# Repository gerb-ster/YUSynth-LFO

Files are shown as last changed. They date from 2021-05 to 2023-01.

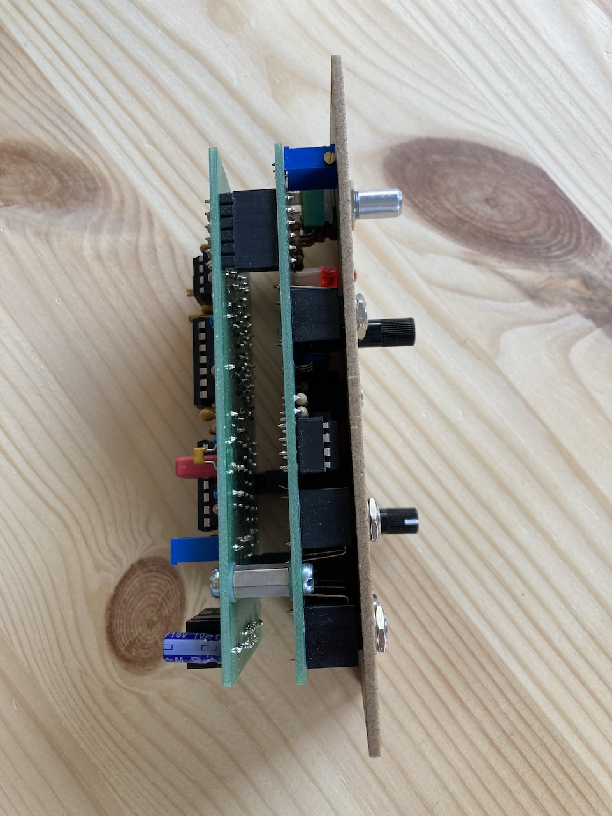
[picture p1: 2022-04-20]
images/IMG_1314.jpeg

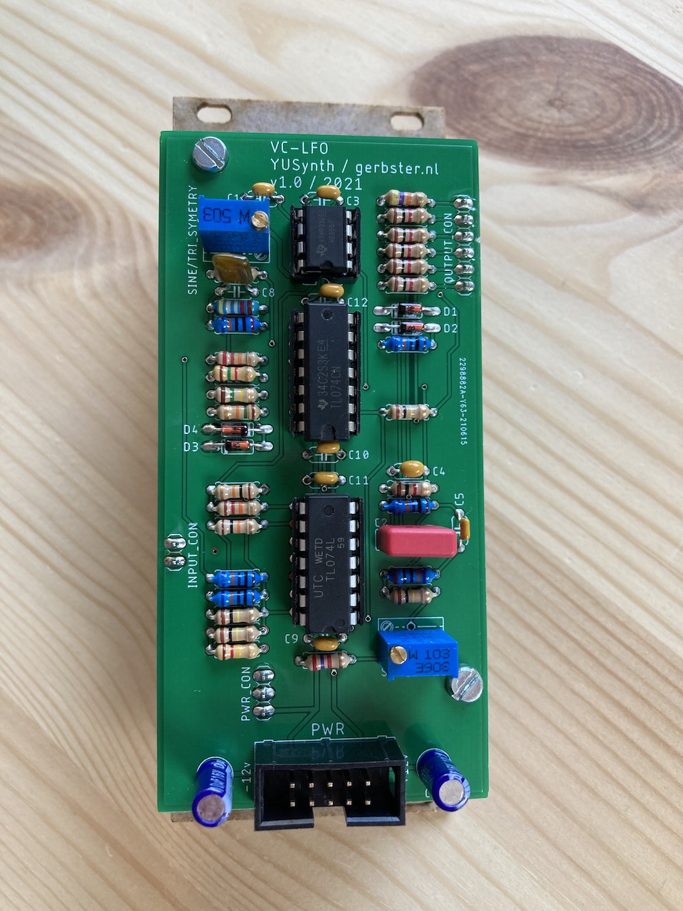
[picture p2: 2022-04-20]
images/IMG_1312.jpeg

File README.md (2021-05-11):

# YUSynth LFO

I'm working on some new modules, one of them is this VC-LFO adaptation from YUSynth. As far as I can determine this is a VCO that generates a saw waveform which is then run thru some wave shapers to create a saw, tri, pulse and sine wave.

I've made some modifications:

- I've powered it with +/- 12v instead of the +/- 15v.
- I've ommited the range switch section, after breadboarding it I found the range with the 1 uF cap quite sufficient.
- I also changed some resistor values to make sure the output is 10vpp around 0v for all waveforms.
- I rearranged the wave shapers a bit; the tri/sine section comes after the saw buffer, this way the tri/sine section outputs a 10vpp around 0v without the need for extra components.

In the YUSynth design there was 1 unused op-amp section; I've used that one to invert the saw into an extra ramp output.

The original design:
http://yusynth.net/Modular/EN/LFO/VC-LFO2.html

## Status: Work in Progress

- done: first schematic & board design
- done: breadboard and test
- done: design frontpanel
- todo: order PCB and build prototype

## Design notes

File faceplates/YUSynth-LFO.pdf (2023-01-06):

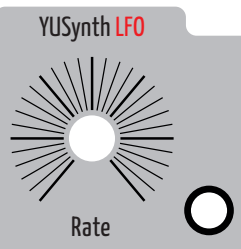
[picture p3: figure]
Rate; YUSynth LFO

Sync.

CV

+
PWM

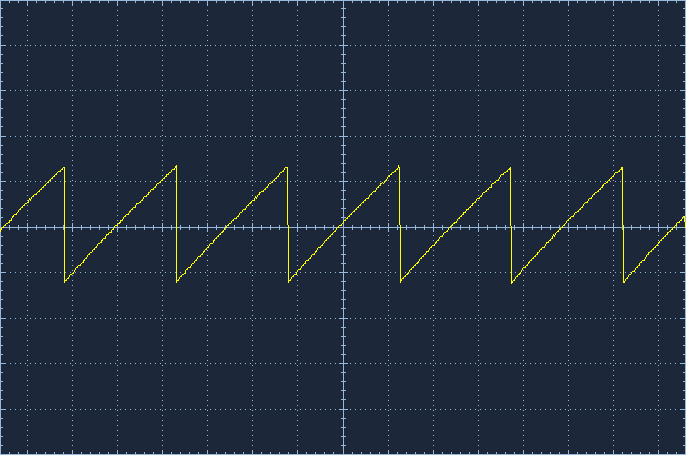
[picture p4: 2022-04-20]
images/saw.png

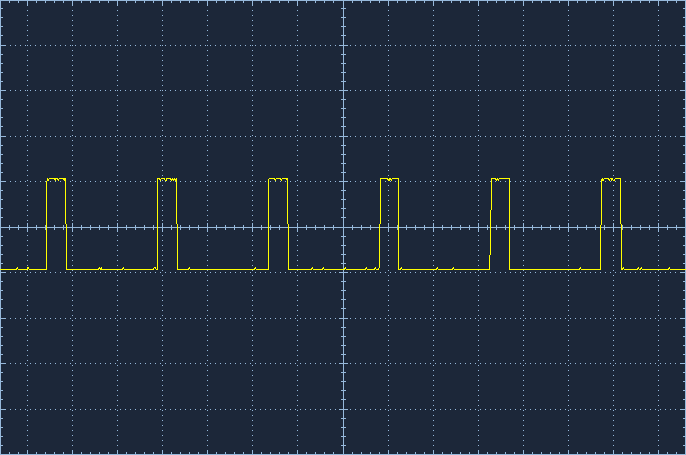
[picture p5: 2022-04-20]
images/pwm.png

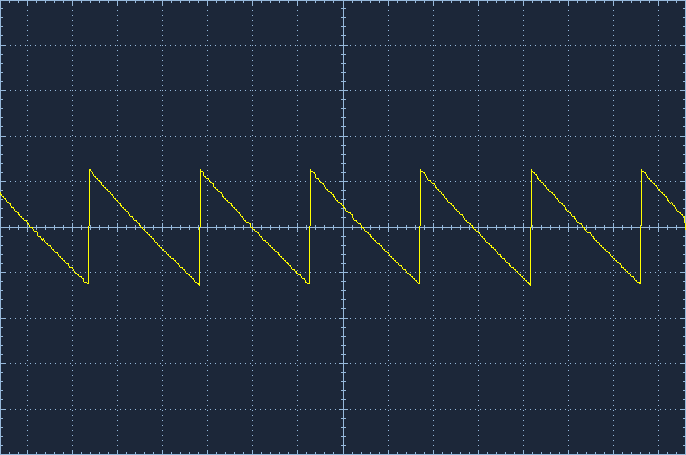
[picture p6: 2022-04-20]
images/r-saw.png

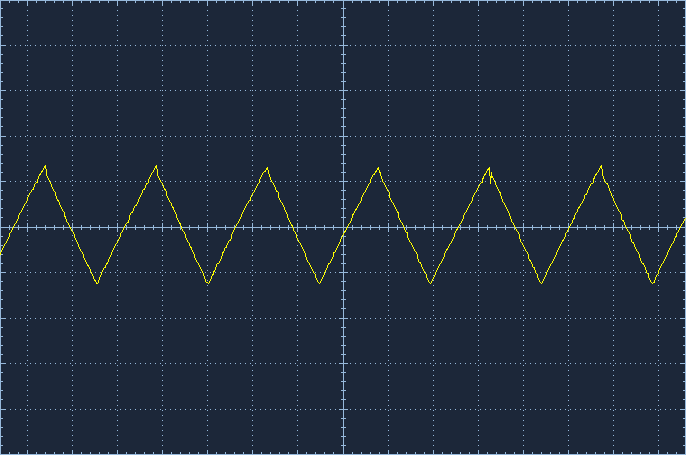
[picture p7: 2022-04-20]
images/tri.png

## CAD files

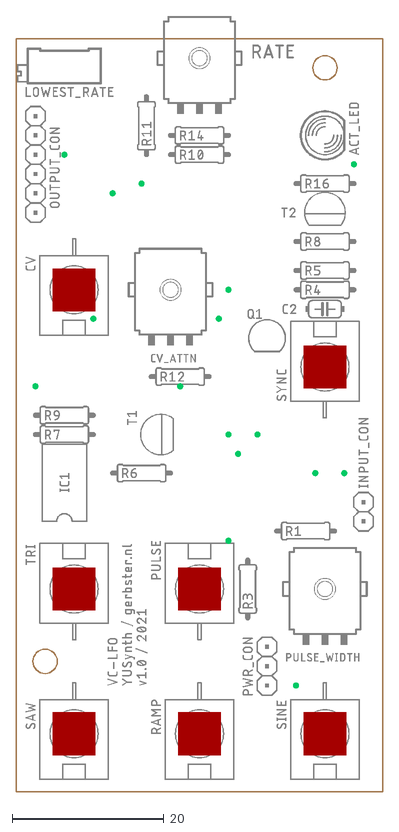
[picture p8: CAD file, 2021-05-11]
faceplates/ioboard.dxf
48.3 x 102.0

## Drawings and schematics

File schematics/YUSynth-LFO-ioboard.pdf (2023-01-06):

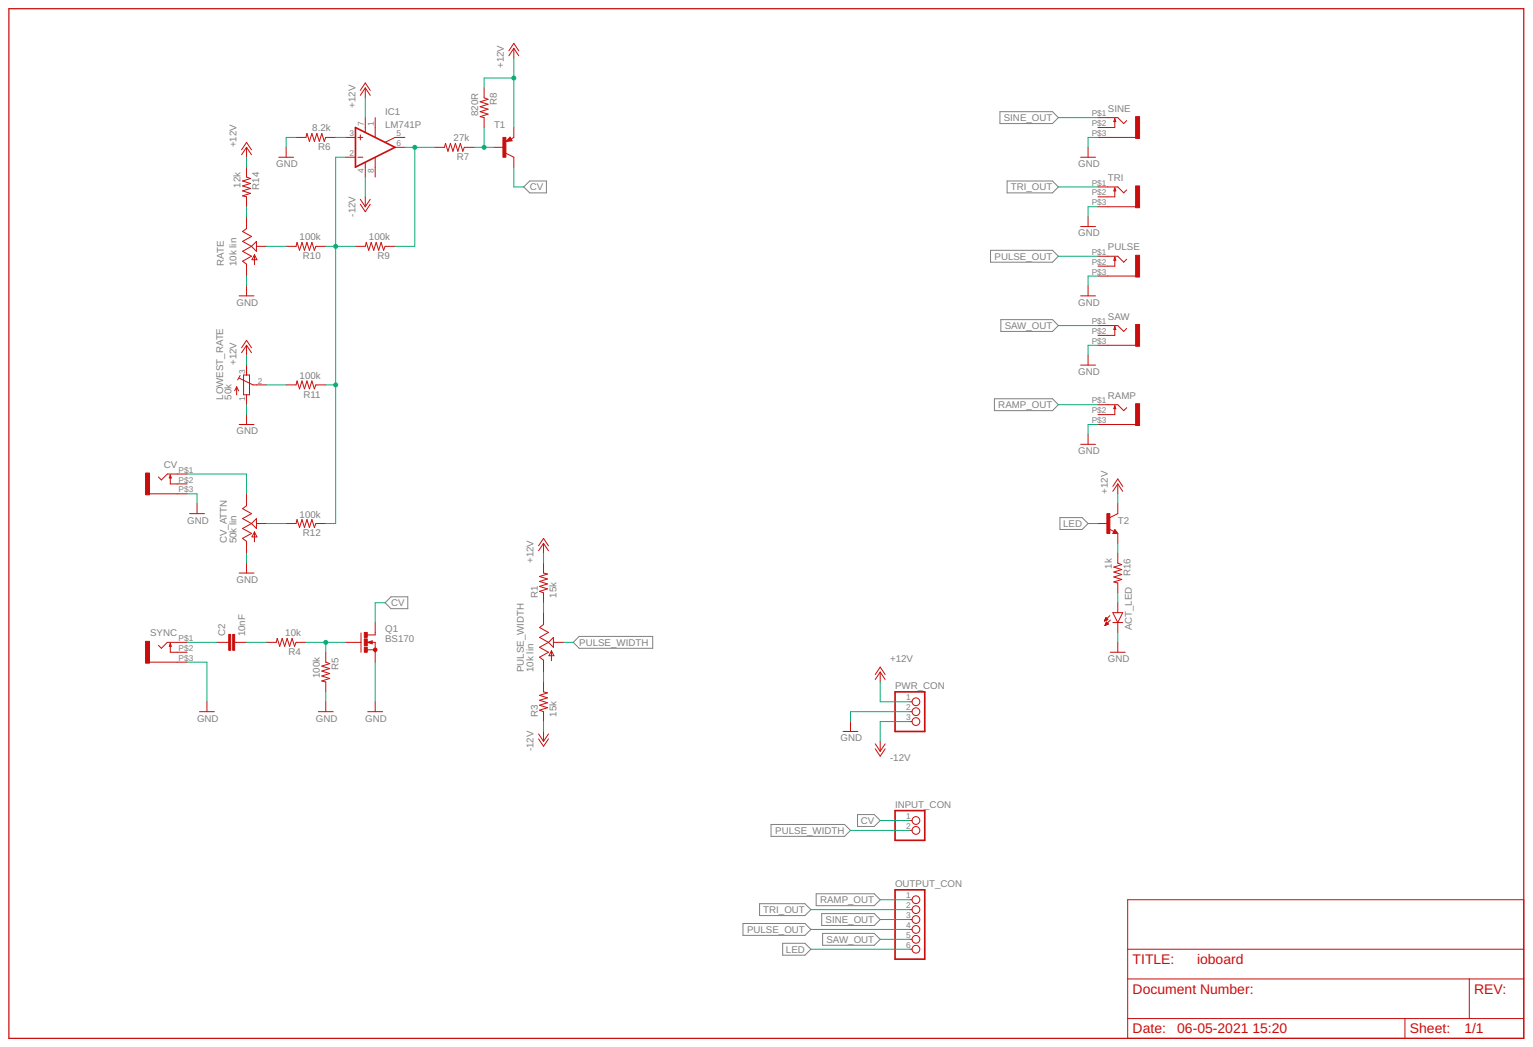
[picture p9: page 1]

15k LM741P +12V -12V GND 10k lin 15k +12V -12V BS170 10nF 10k 100k GND GND GND 8.2k GND 27k 820R 100k +12V 100k 100k 100k 10k lin 12k +12V GND 50k +12V GND 50k lGND in 1k GND +12V GND GND GND GND +12V -12V GND GND P$3 P$1 P$2 SYNC R1 5 1 23 6 8 7 4 IC1 T1 PULSE_WIDTH T2 ACT_LED R3 Q1 C2 R4 R5 R6 R7 R8 R10 R9 R11 R12 RATE R14 1 3 2 LOWEST_RATE P$3 P$1 P$2 CV CV_ATTN R16 P$3 P$1 P$2SINE P$3 P$1 P$2TRI P$3 P$1 P$2PULSE P$3 P$1 P$2SAW 123 PWR_CON P$3 P$1 P$2 RAMP 12 INPUT_CON 123456 OUTPUT_CON PULSE_WIDTH PULSE_WIDTH CV CV CV LED LED SINE_OUT SINE_OUT TRI_OUT TRI_OUT PULSE_OUT PULSE_OUT SAW_OUT SAW_OUT RAMP_OUT RAMP_OUT Date: Sheet: REV: TITLE: Document Number: 06-05-2021 15:20 1/1 ioboard

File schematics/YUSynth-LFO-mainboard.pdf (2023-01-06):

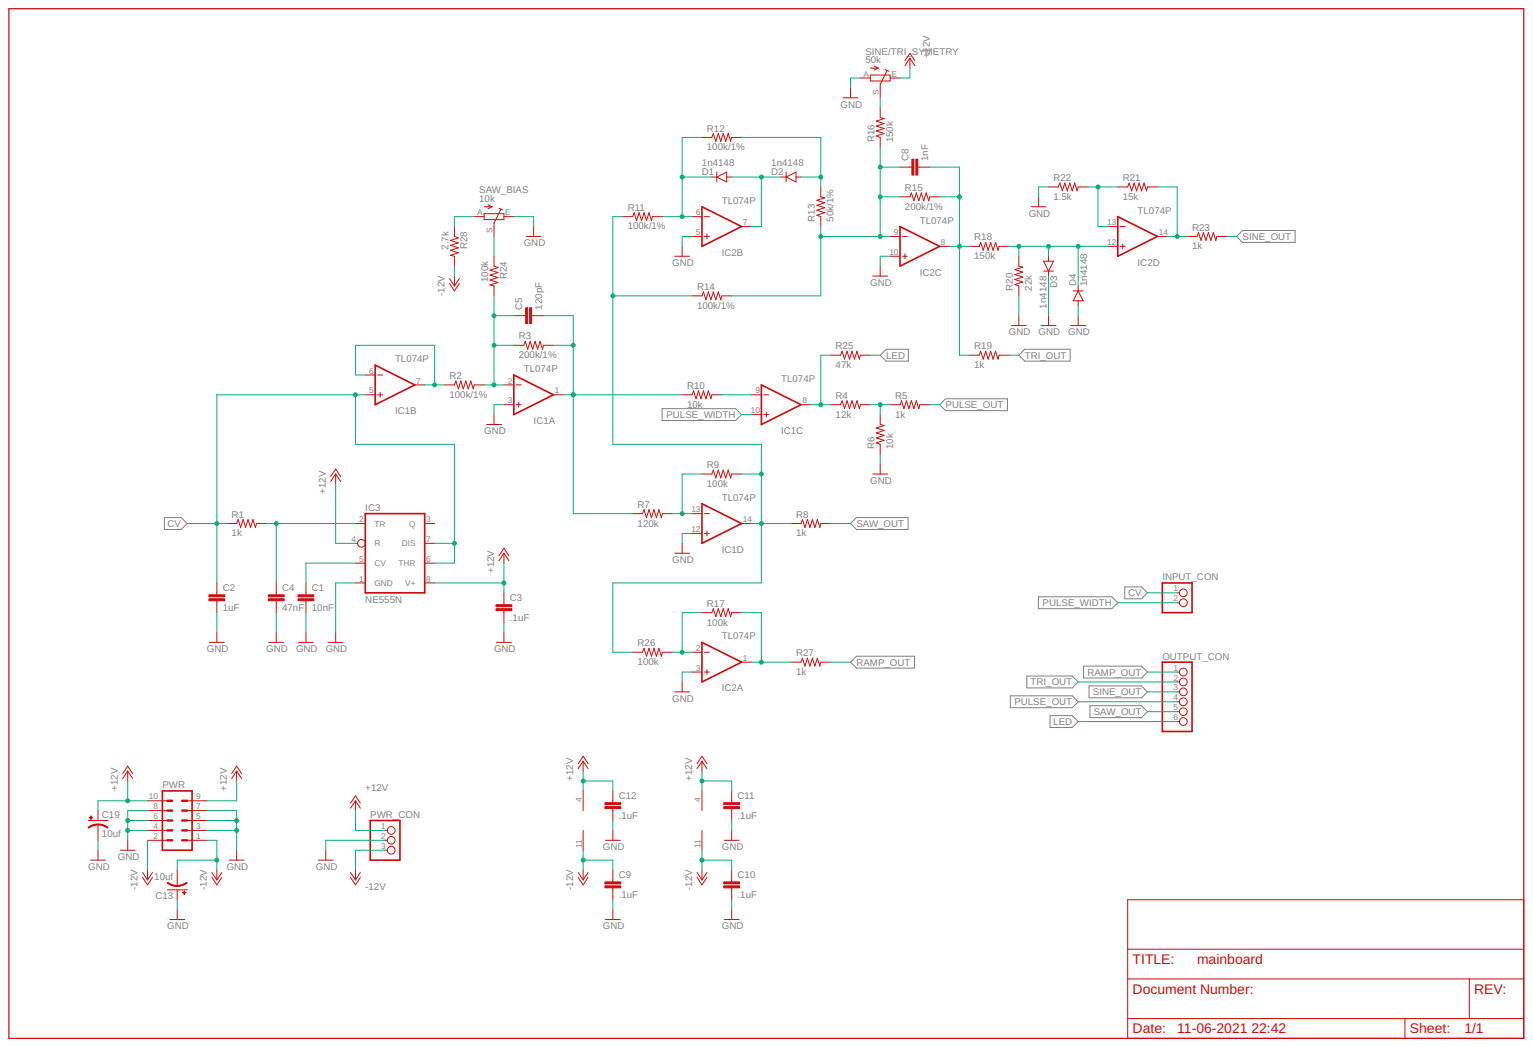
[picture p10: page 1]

Document Number: | REV:

Date: 11-06-2021 22:42 | Sheet: 1/1

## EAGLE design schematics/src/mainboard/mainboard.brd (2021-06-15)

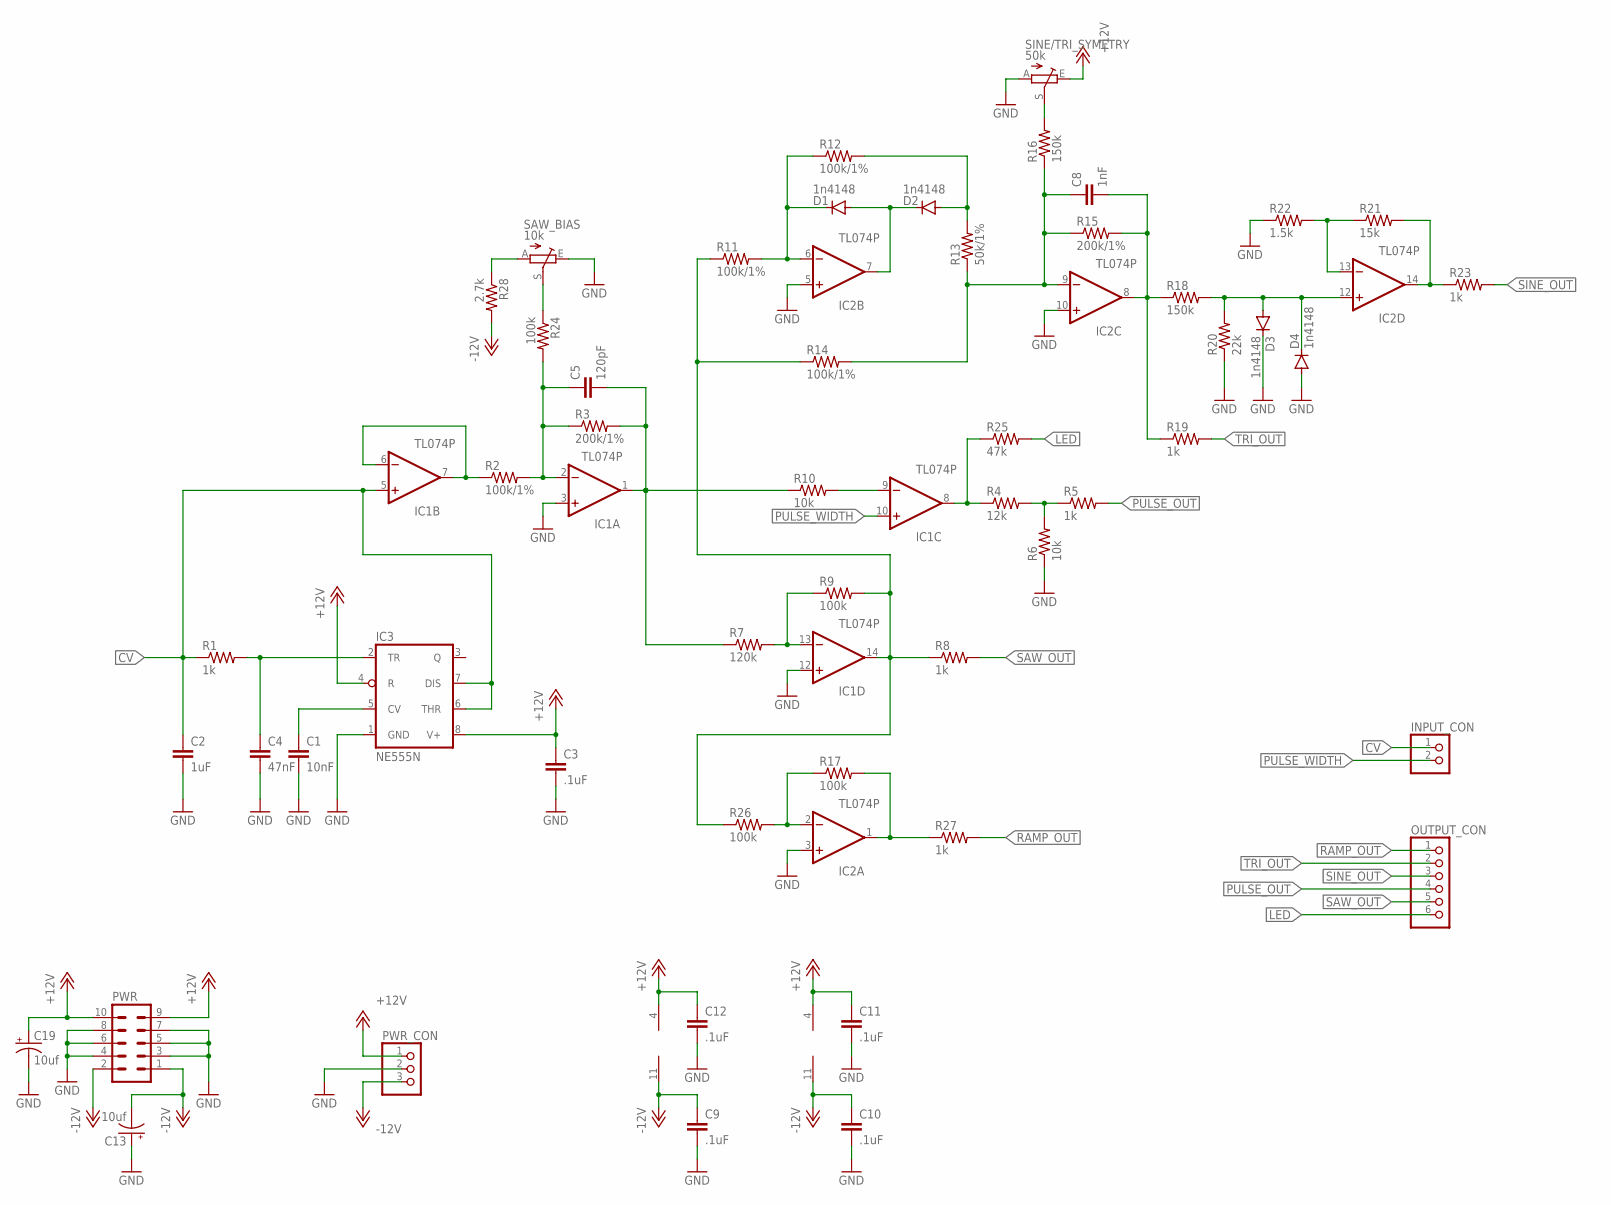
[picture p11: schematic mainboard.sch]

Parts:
C1: 10nF; C050-024X044
C2: 1uF; C075-032X103
C3, C9, C10, C11, C12: .1uF; C050-024X044
C4: 47nF; C050-024X044
C5: 120pF; C050-024X044
C8: 1nF; C050-024X044
C13, C19: 10uf; E2,5-5
D1, D2, D3, D4: 1n4148; DO35-7
IC1, IC2: TL074P; DIL14
IC3: NE555N; DIL08
INPUT_CON: PINHD-1X2; 1X02
OUTPUT_CON: PINHD-1X6; 1X06
PWR: ML10
PWR_CON: PINHD-1X3; 1X03
R1, R5, R8, R19, R23, R27: 1k; 0207/7
R2, R11, R12, R14: 100k/1%; 0207/7
R3, R15: 200k/1%; 0207/7
R4: 12k; 0207/7
R6, R10: 10k; 0207/7
R7: 120k; 0207/7
R9, R17, R24, R26: 100k; 0207/7
R13: 50k/1%; 0207/7
R16, R18: 150k; 0207/7
R20: 22k; 0207/7
R21: 15k; 0207/7
R22: 1.5k; 0207/7
R25: 47k; 0207/7
R28: 2.7k; 0207/7
SAW_BIAS: 10k; S64YW
SINE/TRI_SYMETRY: 50k; S64YW

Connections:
+12V: C3.1, C11.1, C12.1, C19.+, IC1.4 (V+), IC2.4 (V+), IC3.4 (R), IC3.8 (V+), PWR.9, PWR.10, PWR_CON.1, SINE/TRI_SYMETRY.E
-12V: C9.1, C10.1, C13.-, IC1.11 (V-), IC2.11 (V-), PWR.1, PWR.2, PWR_CON.3, R28.2
CV: C2.1, IC1.5 (+IN), IC3.6 (THR), IC3.7 (DIS), INPUT_CON.1, R1.1
GND: C1.2, C2.2, C3.2, C4.2, C9.2, C10.2, C11.2, C12.2, C13.+, C19.-, D3.C, D4.A, IC1.3 (+IN), IC1.12 (+IN), IC2.3 (+IN), IC2.5 (+IN), IC2.10 (+IN), IC3.1 (GND), PWR.3, PWR.4, PWR.5, PWR.6, PWR.7, PWR.8, PWR_CON.2, R6.1, R20.1, R22.1, SAW_BIAS.E, SINE/TRI_SYMETRY.A
LED: OUTPUT_CON.6, R25.2
LED_OUT: IC1.8 (OUT), R4.1, R25.1
unnamed: C1.1, IC3.5 (CV)
unnamed: C4.1, IC3.2 (TR), R1.2
unnamed: IC1.6 (-IN), IC1.7 (OUT), R2.1
unnamed: C5.1, IC1.2 (-IN), R2.2, R3.1, R24.2
unnamed: IC2.2 (-IN), R17.1, R26.2
unnamed: R4.2, R5.1, R6.2
unnamed: R24.1, SAW_BIAS.S
unnamed: C5.2, IC1.1 (OUT), R3.2, R7.1, R10.1
unnamed: IC1.13 (-IN), R7.2, R9.1
unnamed: R28.1, SAW_BIAS.A
unnamed: IC1.9 (-IN), R10.2
unnamed: D1.C, IC2.6 (-IN), R11.2, R12.1
unnamed: C8.1, IC2.9 (-IN), R13.1, R14.2, R15.1, R16.1
unnamed: D1.A, D2.C, IC2.7 (OUT)
unnamed: D2.A, R12.2, R13.2
unnamed: R16.2, SINE/TRI_SYMETRY.S
unnamed: C8.2, IC2.8 (OUT), R15.2, R18.1, R19.1
unnamed: D3.A, D4.C, IC2.12 (+IN), R18.2, R20.2
unnamed: IC2.14 (OUT), R21.2, R23.1
unnamed: IC2.13 (-IN), R21.1, R22.2
unnamed: IC1.14 (OUT), R8.1, R9.2, R11.1, R14.1, R26.1
unnamed: IC2.1 (OUT), R17.2, R27.1
PULSE_OUT: OUTPUT_CON.4, R5.2
PULSE_WIDTH: IC1.10 (+IN), INPUT_CON.2
RAMP_OUT: OUTPUT_CON.1, R27.2
SAW_OUT: OUTPUT_CON.5, R8.2
SINE_OUT: OUTPUT_CON.3, R23.2
TRI_OUT: OUTPUT_CON.2, R19.2

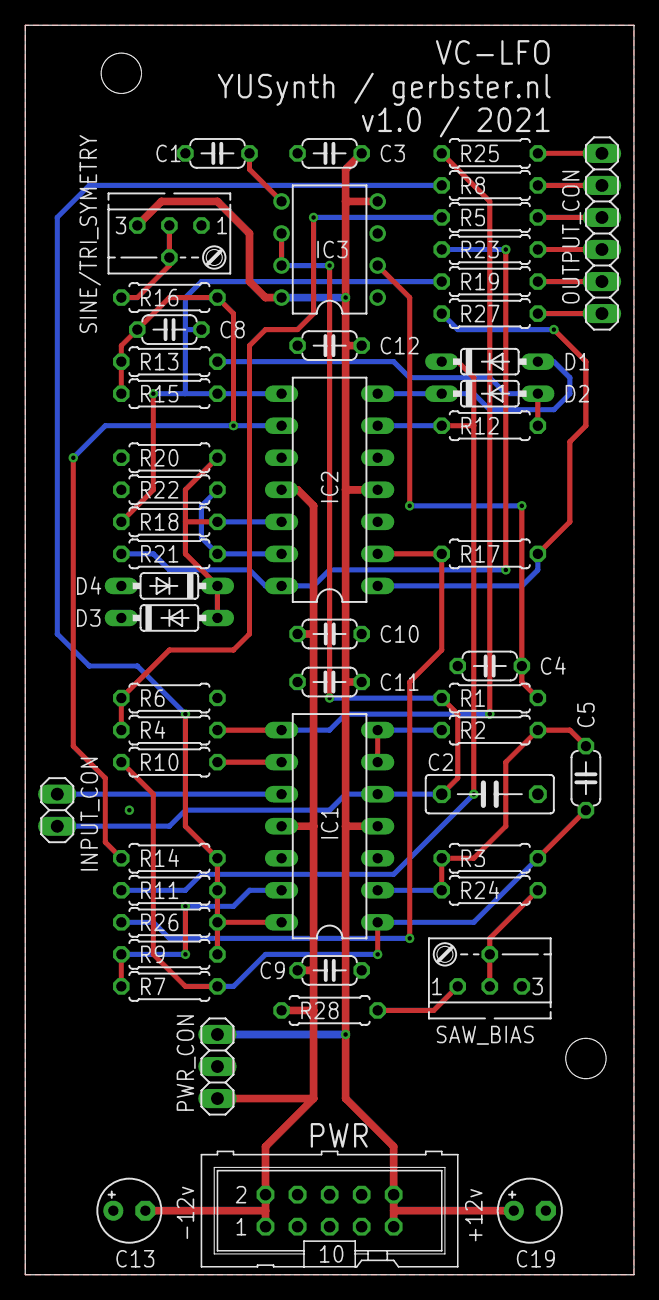
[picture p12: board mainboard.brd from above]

Board: 2 copper layers, 48.3 x 99.1 mm, 53 parts (0 on the bottom side), 34 nets.

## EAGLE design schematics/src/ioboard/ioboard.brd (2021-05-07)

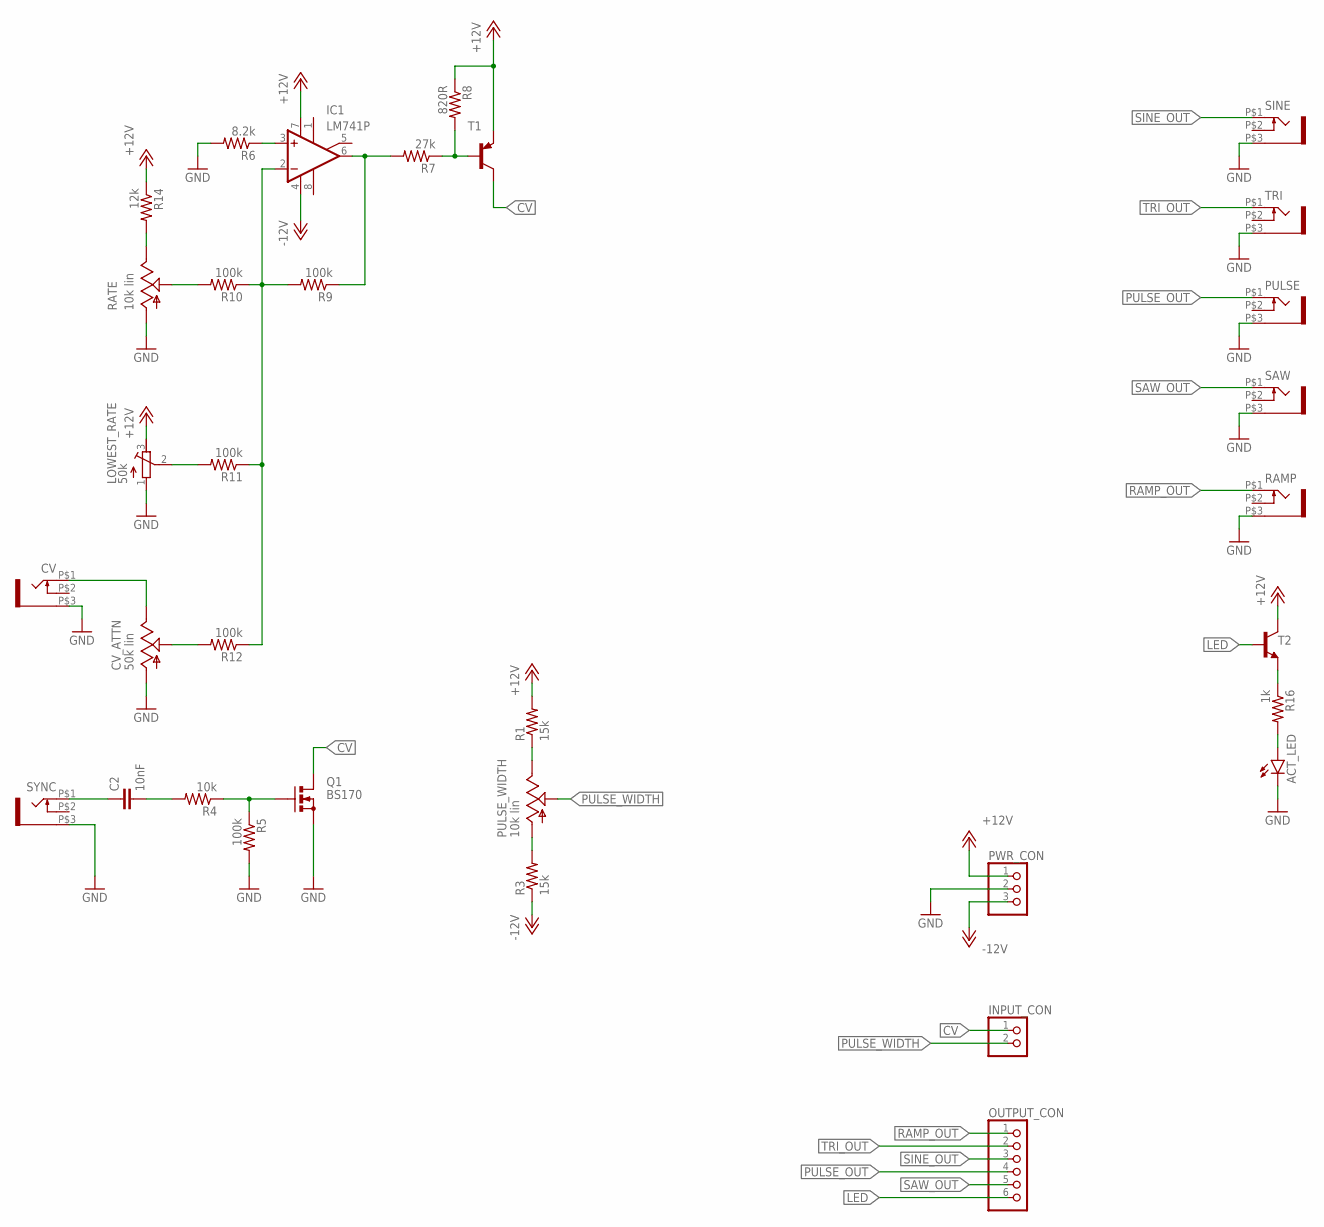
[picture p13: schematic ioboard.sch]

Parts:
ACT_LED: LED5MM
C2: 10nF; C050-024X044
CV: WQP-PJ301M-12_JACK
CV_ATTN: 50k lin; EVUF
IC1: LM741P; DIL08
INPUT_CON: PINHD-1X2; 1X02
LOWEST_RATE: 50k; RTRIM64X
OUTPUT_CON: PINHD-1X6; 1X06
PULSE: WQP-PJ301M-12_JACK
PULSE_WIDTH: 10k lin; EVUF
PWR_CON: PINHD-1X3; 1X03
Q1: BS170; SOT54E
R1, R3: 15k; 0207/7
R4: 10k; 0207/7
R5, R9, R10, R11, R12: 100k; 0207/7
R6: 8.2k; 0207/7
R7: 27k; 0207/7
R8: 820R; 0207/7
R14: 12k; 0207/7
R16: 1k; 0207/7
RAMP: WQP-PJ301M-12_JACK
RATE: 10k lin; EVUF
SAW: WQP-PJ301M-12_JACK
SINE: WQP-PJ301M-12_JACK
SYNC: WQP-PJ301M-12_JACK
T1: BC557C-PNP-TO92-EBC; TO92-EBC
T2: BC547-NPN-TO92-CBE; TO92-CBE
TRI: WQP-PJ301M-12_JACK

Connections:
+12V: IC1.7 (V+), LOWEST_RATE.3 (E), PWR_CON.1, R1.2, R8.1, R14.1, T1.E, T2.C
-12V: IC1.4 (V-), PWR_CON.3, R3.1
CV: INPUT_CON.1, Q1.D, T1.C
GND: ACT_LED.K (C), CV.P$3 (1), CV_ATTN.1 (A), LOWEST_RATE.1 (A), PULSE.P$3 (1), PWR_CON.2, Q1.S, R5.2, R6.2, RAMP.P$3 (1), RATE.1 (A), SAW.P$3 (1), SINE.P$3 (1), SYNC.P$3 (1), TRI.P$3 (1)
LED: OUTPUT_CON.6, T2.B
unnamed: PULSE_WIDTH.1 (A), R3.2
unnamed: PULSE_WIDTH.3 (E), R1.1
unnamed: C2.1, SYNC.P$1 (2)
unnamed: C2.2, R4.2
unnamed: Q1.G, R4.1, R5.1
unnamed: IC1.3 (+IN), R6.1
unnamed: IC1.6 (OUT), R7.2, R9.1
unnamed: R7.1, R8.2, T1.B
unnamed: R14.2, RATE.3 (E)
unnamed: R10.2, RATE.2 (S)
unnamed: IC1.2 (-IN), R9.2, R10.1, R11.1, R12.1
unnamed: LOWEST_RATE.2 (S), R11.2
unnamed: CV_ATTN.2 (S), R12.2
unnamed: CV.P$1 (2), CV_ATTN.3 (E)
unnamed: R16.1, T2.E
unnamed: ACT_LED.A, R16.2
PULSE_OUT: OUTPUT_CON.4, PULSE.P$1 (2)
PULSE_WIDTH: INPUT_CON.2, PULSE_WIDTH.2 (S)
RAMP_OUT: OUTPUT_CON.1, RAMP.P$1 (2)
SAW_OUT: OUTPUT_CON.5, SAW.P$1 (2)
SINE_OUT: OUTPUT_CON.3, SINE.P$1 (2)
TRI_OUT: OUTPUT_CON.2, TRI.P$1 (2)

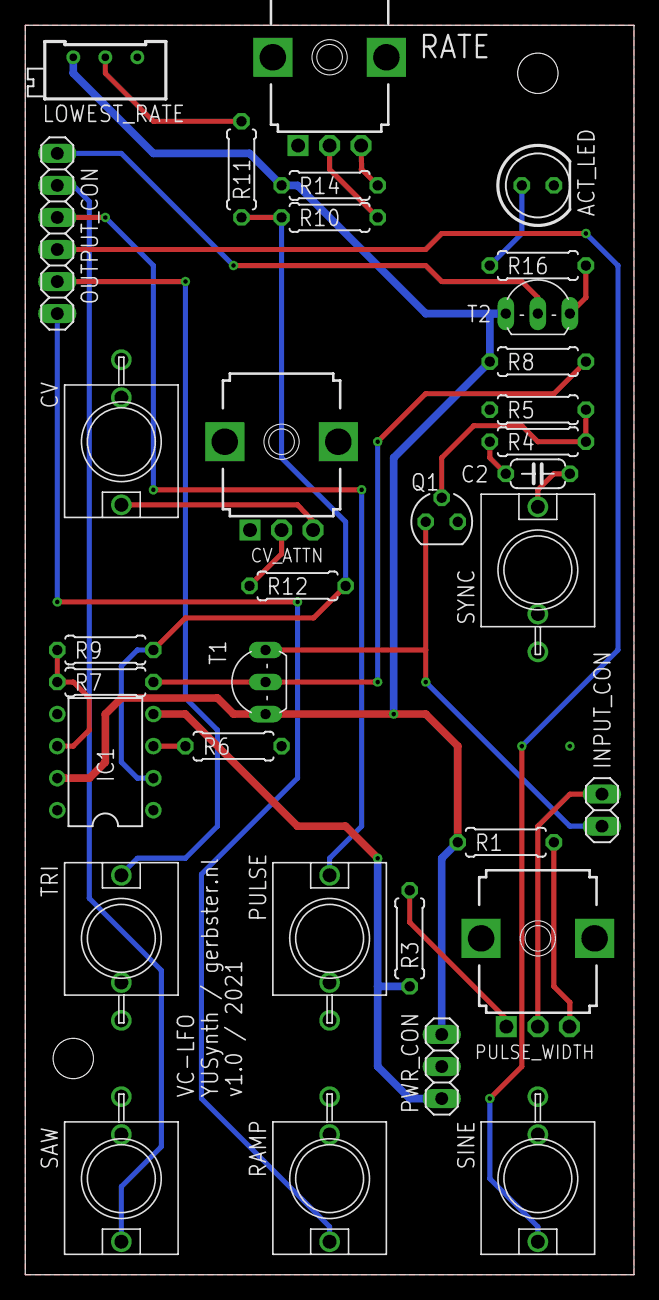
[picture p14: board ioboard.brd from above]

Board: 2 copper layers, 48.3 x 99.1 mm, 33 parts (0 on the bottom side), 27 nets.

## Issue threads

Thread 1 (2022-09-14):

can't find CEM 3310 VCEG

LegendaryTeacherLiu, 2022-09-14:
I can't buy this chip, can I replace it with another model?

gerb-ster, 2022-09-14:
Yes, you can use the AS3310 replacement:

https://www.alfarzpp.lv/eng/sc/AS3310.php

LegendaryTeacherLiu, 2022-09-14:
> 是的，您可以使用 AS3310 替代品：
>
> https://www.alfarzpp.lv/eng/sc/AS3310.php

Thx for your  reply! I can’t find AS3310 too. So sad~

crankery, 2024-03-26:
I know this is a bit old but you can buy those chips at Synthcube in the US, Thonk in the UK and from Erica Synths in Latvia (which is where they're made).

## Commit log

2021-05-06 initial designs
    [YUSynth-LFO-ioboard.brd, YUSynth-LFO-ioboard.sch, YUSynth-LFO-mainboard.brd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]
2021-05-07 Added files & structure
    [ioboard.brd, ioboard.sch, mainboard.brd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]
2021-05-11 Added Status & Images
    [ioboard.dxf]
2021-06-15 Updated Schematics, Fixed Power Socket orientation
    [YUSynth-LFO-ioboard.GBL, YUSynth-LFO-ioboard.GBO, YUSynth-LFO-ioboard.GBP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]
2021-08-06 Updated some schematics and docs
    [YUSynth-LFO-ioboard.GBL, YUSynth-LFO-ioboard.GBO, YUSynth-LFO-ioboard.GBP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]
2021-08-10 Fixed some bugs and updated documentation
    [YUSynth-LFO-ioboard.XLN, YUSynth-LFO-mainboard.XLN, gerber_job.gbrjob]
2022-04-20 Some updates & bugfixes
    [YUSynth-LFO-ioboard.XLN, YUSynth-LFO-mainboard.XLN, gerber_job.gbrjob]
2022-04-22 Fixed schematics & descriptions
    [YUSynth-LFO-ioboard.XLN, YUSynth-LFO-mainboard.XLN, gerber_job.gbrjob]
2022-05-17 Updated Firmware
    [YUSynth-LFO-ioboard.XLN, YUSynth-LFO-mainboard.XLN, gerber_job.gbrjob]
2022-05-18 Updated Faceplates
    [YUSynth-LFO-ioboard.XLN, YUSynth-LFO-mainboard.XLN, gerber_job.gbrjob]
2022-05-18 Fixed issues
    [YUSynth-LFO-ioboard.XLN, YUSynth-LFO-mainboard.XLN, gerber_job.gbrjob]
2022-05-21 Fixed schematics
    [YUSynth-LFO-ioboard.XLN, YUSynth-LFO-mainboard.XLN, gerber_job.gbrjob]
2022-05-28 General updates
    [YUSynth-LFO-ioboard.GKO, YUSynth-LFO-mainboard.GKO, copper_bottom.gbr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]
2022-06-13 Faceplates & Bugfixes
    [drills.xln, gerber_job.gbrjob]
2022-06-26 Fixed faceplate design
    [drills.xln, gerber_job.gbrjob]
